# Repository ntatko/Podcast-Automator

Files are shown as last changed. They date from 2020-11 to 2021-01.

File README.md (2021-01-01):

# Podcast-Automator

This is a simple piece of code that uses a teensy 4.0 board to help my (mostly) blind grandfather use and operate a podcast recorder. I'm using Reaper64 to record his audio. Just hook up some buttons, and be able to control your computer using big, visible arcade buttons. 

## Reaper Setup

Before you can use this, you'll need to add some reaper keyboard shortcuts, by clicking `Options -> Preferences -> Keyboard/Multitouch -> Assign keyboard shortcuts to actions or change existing shortcuts`. It will ask if you want to replace the remove the existing shortcut, just say yes; it's a duplicate shortcut of many.

| COMMAND | KEYBOARD SHORTCUT |
| --- | --- |
| Track: Arm all tracks for recording | Ctrl+9 |
| Track: Unarm all tracks for recording | Ctrl+8 |

## Why this layout?

If you make your own version, you have the right to lay out your buttons any way you choose. That being said, if you're putting your buttons into a project box that has rotational symmetry, take that into consideration. A triangle and a square have different rotational symmetries, so as long as you're holding the sides and the buttons point away from you, you're holding it right.

## Parts List

*To buy*
* [Light up buttons](https://www.amazon.com/gp/product/B06XBLH25X/ref=ppx_yo_dt_b_search_asin_title?ie=UTF8&psc=1)
* [Teensy 4.0](https://www.amazon.com/PJRC-Teensy-4-0-Without-pins/dp/B07W5J3WNH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)
* [Project box](https://www.amazon.com/gp/product/B083HSD9HZ/ref=ppx_yo_dt_b_asin_title_o00_s00?ie=UTF8&psc=1)
* [Terminal block](https://www.amazon.com/gp/product/B076BR7RSH/ref=ppx_yo_dt_b_search_asin_title?ie=UTF8&psc=1)

*Tools, etc*
* Soldering iron, solder, third hand
* Wire stripper
* crimper

I didn't include wire or connectors in this, because you can do whatever you want to connect things: speaker wire or leftover phone cord, terminal connectors or soldered directly, I won't dictate your preference

## Wiring
Fritzing wiring diagram

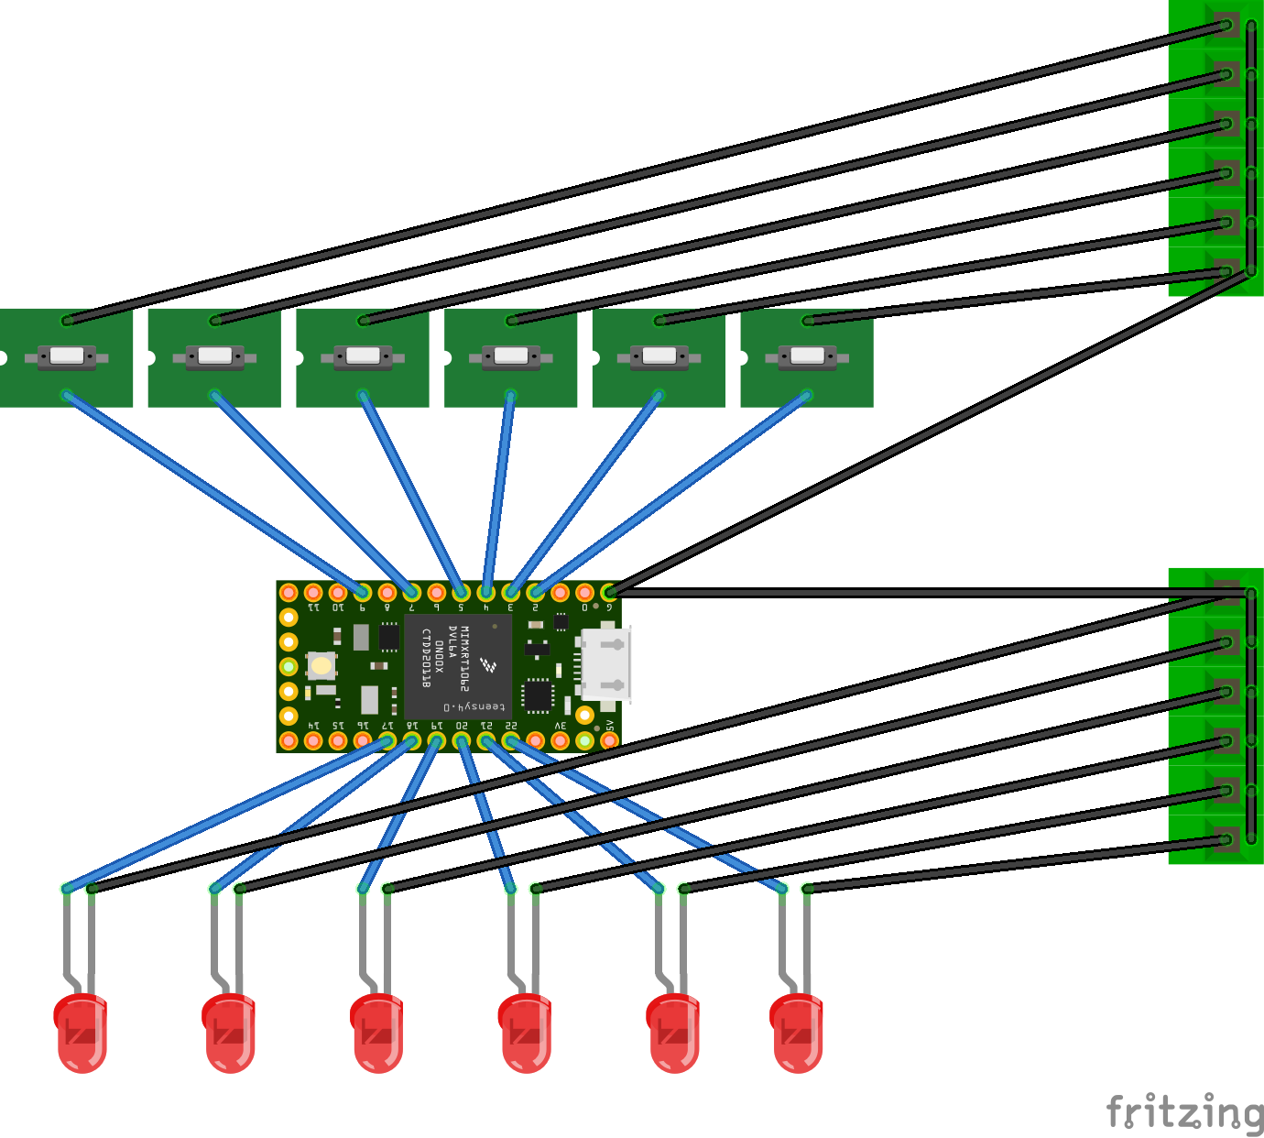
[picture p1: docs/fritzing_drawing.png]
simple fritzing wiring diagram


The teensy and terminal block

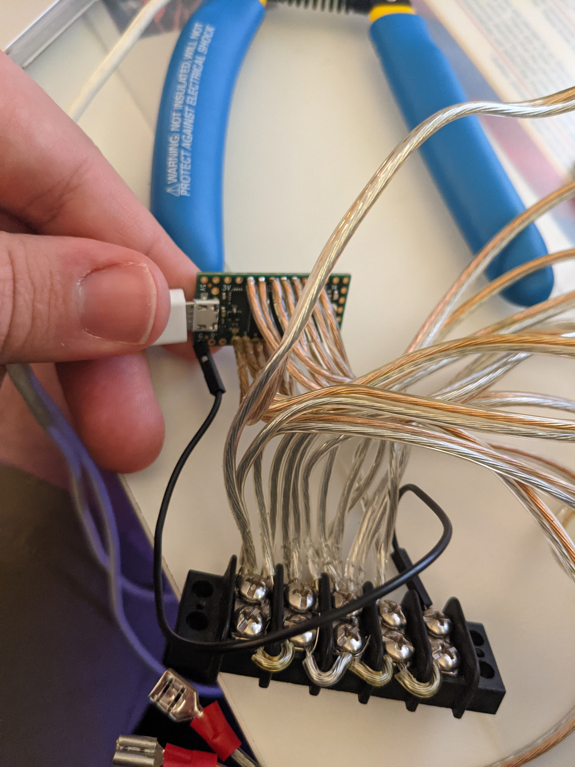
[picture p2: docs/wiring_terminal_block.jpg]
teensy and terminal block


The buttons, all wired up

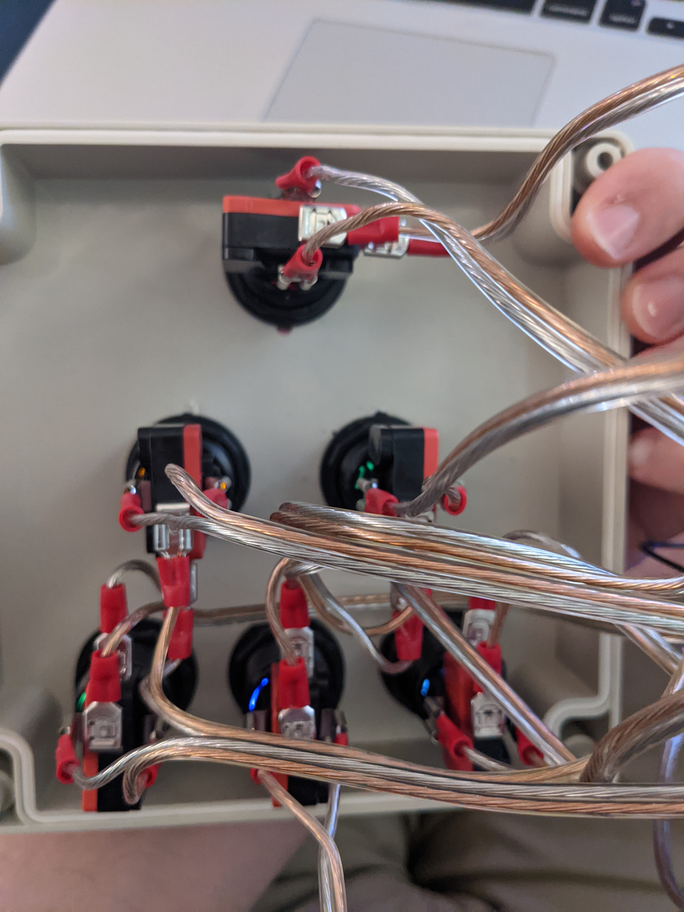
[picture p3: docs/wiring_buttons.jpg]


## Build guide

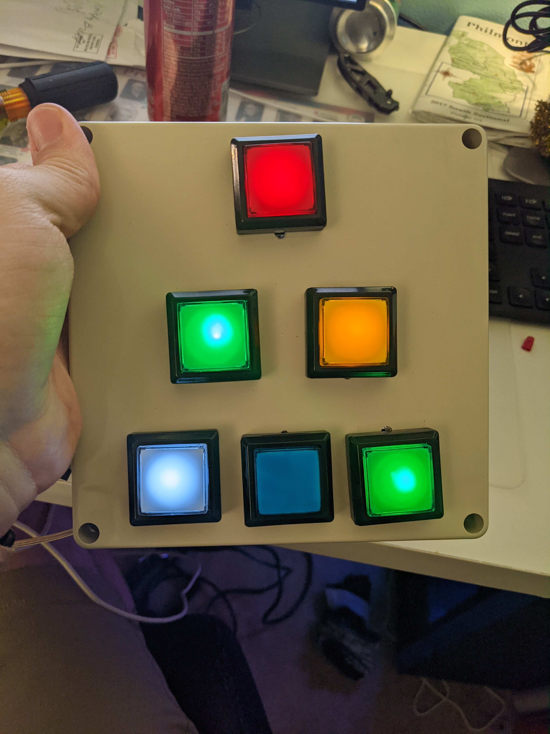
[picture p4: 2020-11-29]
docs/wiring_button_face.jpg

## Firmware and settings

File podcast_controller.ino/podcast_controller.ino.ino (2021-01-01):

#include <EEPROM.h>
#include <Bounce2.h>

bool readyToRecord = false;
bool recording = false;
bool isRecorded = false;
bool isSaved = false;

Bounce button_openProgram = Bounce();
Bounce button_startRecording = Bounce();
Bounce button_saveRecording = Bounce();
Bounce button_playbackRecording = Bounce();
Bounce button_deleteRecording = Bounce();
Bounce button_reset = Bounce();

const int PIN_deleteRecording = 2;
const int PIN_openProgram = 3;
const int PIN_reset = 4;
const int PIN_startRecording = 5;
const int PIN_saveRecording = 9;
const int PIN_playbackRecording = 7;

const int led_deleteRecording = 22;
const int led_openProgram = 21;
const int led_reset = 20;
const int led_startRecording = 19;
const int led_saveRecording = 17;
const int led_playbackRecording = 18;

int lights[] = { led_openProgram, led_startRecording, led_saveRecording, led_playbackRecording, led_deleteRecording, led_reset };
bool isNotOpenLights[sizeof(lights)] = { true, true, true, true, true, true };
bool readyLights[sizeof(lights)] = { true, true, false, false, false, true };
bool recordingLights[sizeof(lights)] = { false, true, false, false, false, true };
bool isRecordedLights[sizeof(lights)] = { true, false, true, true, true, true, true };

void setup() {
  // put your setup code here, to run once:

  button_openProgram.attach(PIN_openProgram, INPUT_PULLUP);
  button_startRecording.attach(PIN_startRecording, INPUT_PULLUP);
  button_saveRecording.attach(PIN_saveRecording, INPUT_PULLUP);
  button_playbackRecording.attach(PIN_playbackRecording, INPUT_PULLUP);
  button_deleteRecording.attach(PIN_deleteRecording, INPUT_PULLUP);
  button_reset.attach(PIN_reset, INPUT_PULLUP);
  
  button_openProgram.interval(25);
  button_startRecording.interval(25);
  button_saveRecording.interval(25);
  button_playbackRecording.interval(25);
  button_deleteRecording.interval(25);
  button_reset.interval(25);

//  pinMode(PIN_deleteRecording, INPUT_PULLUP);
//  pinMode(PIN_openProgram, INPUT_PULLUP);
//  pinMode(PIN_reset, INPUT_PULLUP);
//  pinMode(PIN_startRecording, INPUT_PULLUP);
//  pinMode(PIN_saveRecording, INPUT_PULLUP);
//  pinMode(PIN_playbackRecording, INPUT_PULLUP);
  
  pinMode(led_openProgram, OUTPUT);
  pinMode(led_startRecording, OUTPUT);
  pinMode(led_saveRecording, OUTPUT);
  pinMode(led_playbackRecording, OUTPUT);
  pinMode(led_deleteRecording, OUTPUT);
  pinMode(led_reset, OUTPUT);

  Serial.begin(9600);

  // TEST SEQUENCE - DELTE
  delay(1000); // need to wait after being plugged in to init USB keyboard connection

  digitalWrite(led_openProgram , HIGH);
  digitalWrite(led_startRecording , HIGH);
  digitalWrite(led_saveRecording , HIGH);
  digitalWrite(led_playbackRecording , HIGH);
  digitalWrite(led_deleteRecording , HIGH);
  digitalWrite(led_reset , HIGH);

  Serial.println("Starting");
  
//  openProgram();
//  delay(5000);
//  startRecording();
//  delay(4000);
//  stopRecording();
//  playbackRecording();
//  delay(4000);
//  saveRecording();
//  delay(2000);
//  resetEverything();
//  copyTimeDate();
}

void loop() {
  button_openProgram.update();
  button_startRecording.update();
  button_saveRecording.update();
  button_playbackRecording.update();
  button_deleteRecording.update();
  button_reset.update();

  Serial.print("data: \treset: ");
  Serial.print(digitalRead(PIN_reset));
  Serial.print("\topen: ");
  Serial.print(digitalRead(PIN_openProgram));
  Serial.print("\tstart: ");
  Serial.print(digitalRead(PIN_startRecording));
  Serial.print("\tplayback: ");
  Serial.print(digitalRead(PIN_playbackRecording));
  Serial.print("\tdelete: ");
  Serial.print(digitalRead(PIN_deleteRecording));
  Serial.print("\tsave: ");
  Serial.println(digitalRead(PIN_saveRecording));

  if ( button_reset.fell() ) {
    resetEverything();
    updateLeds();
  } else if ( button_openProgram.fell() && !recording ) {
    Serial.println("pressed open");
    openProgram();
    updateLeds();
  } else if ( button_startRecording.fell() && !recording && readyToRecord ) {
    Serial.println("pressed start");
    startRecording();
    updateLeds();
  } else if ( button_startRecording.fell() && recording ) {
    Serial.println("pressed stop");
    stopRecording();
    updateLeds();
  } else if ( button_playbackRecording.fell() && isRecorded ) {
    Serial.println("pressed playback");
    playbackRecording();
    updateLeds();
  } else if ( button_deleteRecording.fell() && isRecorded ) {
    Serial.println("pressed delete");
    deleteRecording();
    updateLeds();
  } else if ( button_saveRecording.fell() && isRecorded ) {
    Serial.println("pressed save");
    saveRecording();
    deleteRecording();
    updateLeds();
  }
  delay(10);
}

void resetEverything() {
  // Windows kill task
  Keyboard.press(MODIFIERKEY_ALT);
  Keyboard.press(KEY_F4);
  Keyboard.release(MODIFIERKEY_ALT);
  Keyboard.release(KEY_F4);

  delay(100);

  // prompt asking for saving
  Keyboard.press(KEY_N);
  Keyboard.release(KEY_N);

  //reset leds here manually
  resetLeds();

  readyToRecord = false;
  recording = false;
  isRecorded = false;
  isSaved = false;
}

void openProgram() {
  // Windows start reaper program
  Keyboard.press(MODIFIERKEY_RIGHT_GUI);
  Keyboard.release(MODIFIERKEY_RIGHT_GUI);
  delay(2000);
  Keyboard.println("reaper");
  delay(1000);
  Keyboard.press(KEY_ENTER);
  Keyboard.release(KEY_ENTER);

  // wait 10 seconds for the program to open
  delay(5000);

  // create track within reaper
  Keyboard.press(MODIFIERKEY_CTRL);
  Keyboard.press(KEY_T);
  delay(100);
  Keyboard.release(MODIFIERKEY_CTRL);
  Keyboard.release(KEY_T);
  

  //TODO - might need something here to dismiss a notification

  readyToRecord = true;
  recording = false;
  isRecorded = false;
  isSaved = false;
}

void startRecording() {

  // mute speakers
  Keyboard.press(KEY_MEDIA_MUTE);
  Keyboard.release(KEY_MEDIA_MUTE);

  // arm track for recording
  // TODO - make a keybinding within the app that responds to CTRL+9 which arms all tracks for recording
  Keyboard.press(MODIFIERKEY_CTRL);
  Keyboard.press(KEY_9);
  delay(100);
  Keyboard.release(MODIFIERKEY_CTRL);
  Keyboard.release(KEY_9);

  // Start recording
  Keyboard.press(MODIFIERKEY_CTRL);
  Keyboard.press(KEY_R);
  delay(100);
  Keyboard.release(MODIFIERKEY_CTRL);
  Keyboard.release(KEY_R);

  readyToRecord = false;
  recording = true;
}

void stopRecording() {

  // stop recording
  Keyboard.press(MODIFIERKEY_CTRL);
  Keyboard.press(KEY_R);
  delay(100);
  Keyboard.release(MODIFIERKEY_CTRL);
  Keyboard.release(KEY_R);

  // unarm track for recording
  // TODO - make a keybinding in the app that responds to CTRL+8 which un arms all tracks for recording
  Keyboard.press(MODIFIERKEY_CTRL);
  Keyboard.press(KEY_8);
  delay(100);
  Keyboard.release(MODIFIERKEY_CTRL);
  Keyboard.release(KEY_8);

  // unmute speakers
  Keyboard.press(KEY_MEDIA_MUTE);
  Keyboard.release(KEY_MEDIA_MUTE);

  isRecorded = true;
  recording = false;
}

void playbackRecording() {

  Keyboard.press(KEY_SPACE);
  Keyboard.release(KEY_SPACE);
}

void saveRecording() {
  // Right now, I'm using google drive, things automatically show up in a folder. Tab and shift+tab can be used

  // Technically called "render", pulls up a prompt
  Keyboard.press(MODIFIERKEY_CTRL);
  Keyboard.press(MODIFIERKEY_ALT);
  Keyboard.press(KEY_R);
  delay(100);
  Keyboard.release(MODIFIERKEY_CTRL);
  Keyboard.release(MODIFIERKEY_ALT);
  Keyboard.release(KEY_R);

  // Fill out render options prompt
  copyTimeDate();
  delay(1000);
  Keyboard.press(MODIFIERKEY_CTRL);
  Keyboard.press(KEY_V);
  delay(!00);
  Keyboard.release(MODIFIERKEY_CTRL);
  Keyboard.release(KEY_V);
  delay(100);
  Keyboard.press(KEY_ENTER);
  delay(100);
  Keyboard.release(KEY_ENTER);

  // wait for file to finish rendering
  delay(10000); // 10 seconds, might need more

  Keyboard.press(KEY_ENTER);
  Keyboard.release(KEY_ENTER);

  isRecorded = false;
  isSaved = true;
}

void deleteRecording() {

  // delete all tracks
  Keyboard.press(MODIFIERKEY_CTRL);
  Keyboard.press(KEY_A);
  delay(100);
  Keyboard.release(MODIFIERKEY_CTRL);
  Keyboard.release(KEY_A);
  delay(100);
  Keyboard.press(KEY_DELETE);
  Keyboard.release(KEY_DELETE);

//  // reaper will want confirmation
//  delay(200);
//  Keyboard.press(KEY_ENTER);
//  Keyboard.release(KEY_ENTER);

  readyToRecord = true;
  recording = false;
  isRecorded = false;
  isSaved = false;
}

void updateLeds() {

  if (readyToRecord && !recording && !isRecorded ) {
    digitalWrite(led_startRecording, HIGH);
    digitalWrite(led_reset, HIGH);

    digitalWrite(led_deleteRecording, LOW);
    digitalWrite(led_openProgram, LOW);
    digitalWrite(led_saveRecording, LOW);
    digitalWrite(led_playbackRecording, LOW);
  } else if ( !readyToRecord && recording && !isRecorded ) {
    digitalWrite(led_startRecording, HIGH);
    
    digitalWrite(led_reset, LOW);
    digitalWrite(led_deleteRecording, LOW);
    digitalWrite(led_openProgram, LOW);
    digitalWrite(led_saveRecording, LOW);
    digitalWrite(led_playbackRecording, LOW);
  } else if ( !readyToRecord && !recording && isRecorded ) {
    digitalWrite(led_startRecording, LOW);
    digitalWrite(led_openProgram, LOW);
    
    digitalWrite(led_reset, HIGH);
    digitalWrite(led_deleteRecording, HIGH);
    digitalWrite(led_saveRecording, HIGH);
    digitalWrite(led_playbackRecording, HIGH);
  }
}

String generateRecordingName(){
  int generated=0;
  String string = "";
  while ( generated < 6 ) {
    byte randomValue = random(0, 26);
    char letter = randomValue + 'a';
    string += letter;
    generated ++;
  }
  return string;
 }

 void resetLeds() {
  digitalWrite(led_startRecording, HIGH);
  digitalWrite(led_openProgram, HIGH);
  digitalWrite(led_reset, HIGH);
  digitalWrite(led_deleteRecording, HIGH);
  digitalWrite(led_saveRecording, HIGH);
  digitalWrite(led_playbackRecording, HIGH);
 }

 void copyTimeDate() {
  Keyboard.press(MODIFIERKEY_RIGHT_GUI);
  delay(10);
  Keyboard.release(MODIFIERKEY_RIGHT_GUI);
  delay(2000);
  Keyboard.print("powershell");
  delay(100);
  Keyboard.press(KEY_ENTER);
  Keyboard.release(KEY_ENTER);
  delay(2000);
  Keyboard.println("$currDate = Get-Date -Format \"yyyy-MM-dd.HH.mm\"");
  delay(100);
  Keyboard.println("$currDate + \" podcast recording\" | clip");
  delay(100);
  Keyboard.println("exit");
  delay(100);
 }

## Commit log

2020-11-29 led functionality
2020-11-29 and there's the last little bit
    [fritzing_layout.fzz]
2021-01-01 copy timestamp from powershell
